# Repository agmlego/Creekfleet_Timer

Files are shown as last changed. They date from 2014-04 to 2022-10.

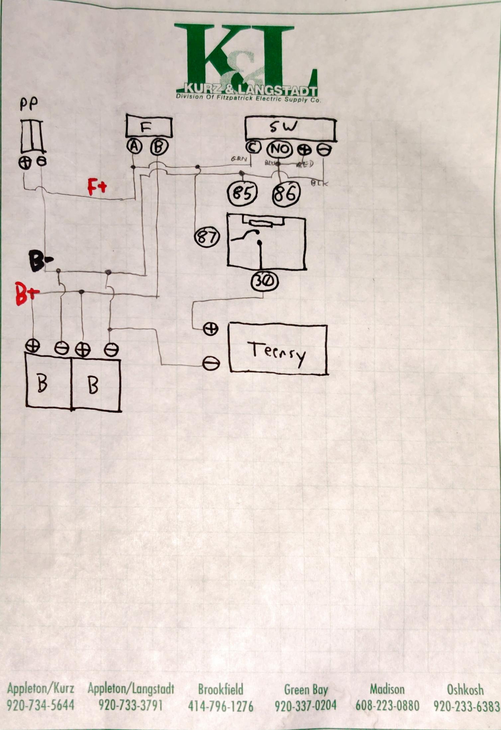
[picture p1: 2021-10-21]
hardware/electrical/battery_harness_schematic.jpg

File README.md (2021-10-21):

Creekfleet Timer
================

Automated start sequencer for the [Creekfleet](https://creekfleet.org) sailing group.

By default, runs the following sequence for each of the number of requested starts:

| Horns | Time to start |
| --- | --- |
| 3 long | 3:00 |
| 2 long | 2:00 |
| 1 long, 3 short | 1:30 |
| 1 long | 1:00 |
| 3 short | 0:30 |
| 2 short | 0:20 |
| 1 short | 0:10 |
| 1 short | 0:05 |
| 1 short | 0:04 |
| 1 short | 0:03 |
| 1 short | 0:02 |
| 1 short | 0:01 |
| 1 long | START |

Also has a mode selectable during idle operation for the ISAF Rule 26 start:

| Horns | Time to start |
| --- | --- |
| 1 short | 5:00 |
| 1 short | 4:00 |
| 1 long | 1:00 |
| 1 short | START |

## Pins

| Function | Arduino Pin |
| --- | --- |
| Horn | D12 |
| Compressor | D11 |
| Pressure Gauge| D35 (A16) |
| UP.LED | D24 |
| UP.Switch | D25 (active low) |
| DOWN.LED | D26 |
| DOWN.Switch | D27 (active low) |
| SELECT.LED | D28 |
| SELECT.Switch | D29 (active low) |
| BACK.LED | D30 |
| BACK.Switch | D31 (active low) |
| LCD.VO | A22 (DAC1) |
| LCD.RS | D13 |
| LCD.RW | D14 |
| LCD.E | D15 |
| LCD.DB0 | D16 |
| LCD.DB1 | D17 |
| LCD.DB2 | D18 |
| LCD.DB3 | D19 |
| LCD.DB4 | D20 |
| LCD.DB5 | D21 |
| LCD.DB6 | D22 |
| LCD.DB7 | D23 |
| LCD.Red BL | D36 (PWM) |
| LCD.Green BL  | D38 (PWM) |
| LCD.Blue BL | D37 (PWM) |

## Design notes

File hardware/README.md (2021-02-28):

Creekfleet Timer Hardware
=========================

EAGLE design files, case CAD files.

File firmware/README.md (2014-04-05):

Creekfleet Timer Firmware
=========================

Arduino 1.0.5 code.

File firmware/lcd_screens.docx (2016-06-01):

0123456789ABCDEFGHIJ

A CreekFleet Start

B Sequencer v2.0

C agmlego@gmail.com

D http://bit.ly/123456

0123456789ABCDEFGHIJ

A

B Number of Starts?

C > 10 <

D [UP] [DOWN] [SEL]

0123456789ABCDEFGHIJ

A Start 1/10

B 2:59 to start

C Bat 13.6V Air 89.7

D [STOP][RECALL][BLIP]

0123456789ABCDEFGHIJ

A Lock 2 HH:MM:SS.S

B Lock 1 HH:MM:SS.S

C > Live HH:MM:SS.S <

D [STOP][RECALL][BLIP]

0123456789ABCDEFGHIJ

A Short horn 250ms

B Long horn 500ms

C > Horn gap 250ms <

D [UP] [DOWN] [SEL]

0123456789ABCDEFGHIJ

A Air hyst. 20psi

B Volt warn 12.1V

C > Flag speed 250ms <

D [UP] [DOWN] [SEL]

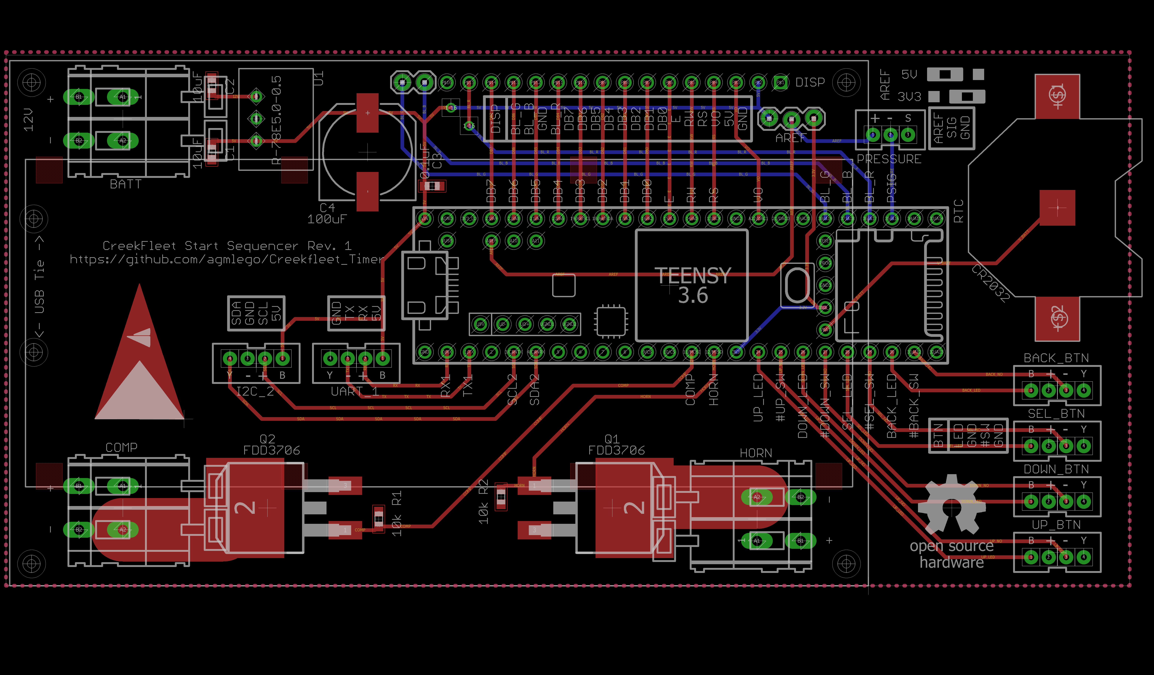
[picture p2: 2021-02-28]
hardware/electrical/mainboard_brd.png

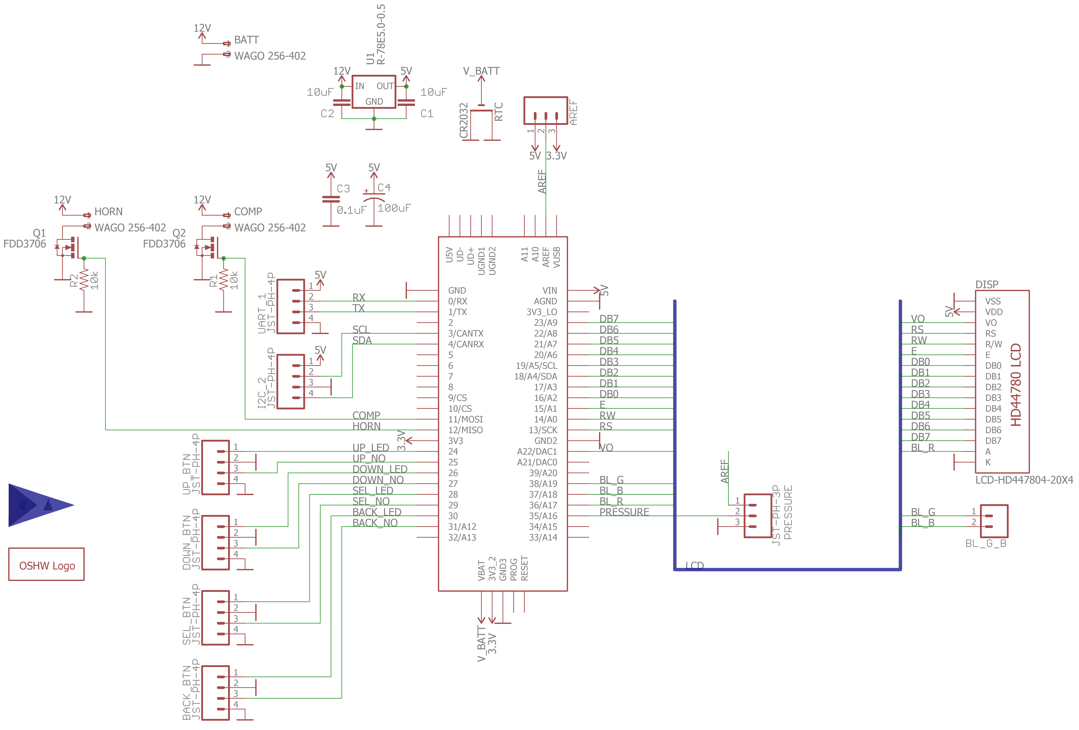
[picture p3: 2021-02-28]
hardware/electrical/mainboard_sch.png

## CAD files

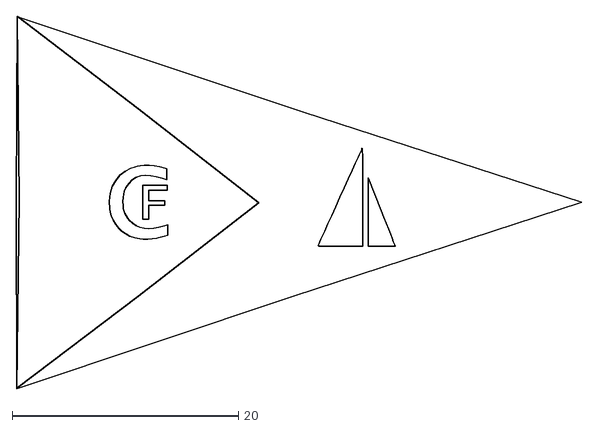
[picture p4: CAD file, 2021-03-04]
hardware/mechanical/creekfleet_logo.dxf
50.0 x 32.9

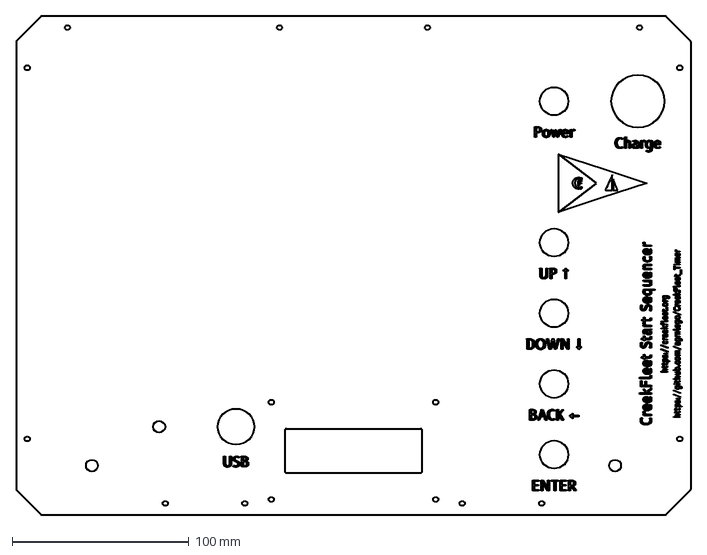
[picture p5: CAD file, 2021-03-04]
hardware/mechanical/case_panel.dxf
382.0 x 282.0 mm

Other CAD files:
hardware/mechanical/case_panel.dwg
hardware/mechanical/case_panel.ipt

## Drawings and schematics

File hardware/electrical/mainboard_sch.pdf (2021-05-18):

2021-03-12 23:05 C:\Users\agmlego\Sync\rwsir-rc7py\projects\CreekFleet\Creekfleet_Timer\hardware\electrical\mainboard.sch (Sheet: 1/1) LCD⁻HD⁴⁴⁷⁸⁰⁴⁻²⁰X4

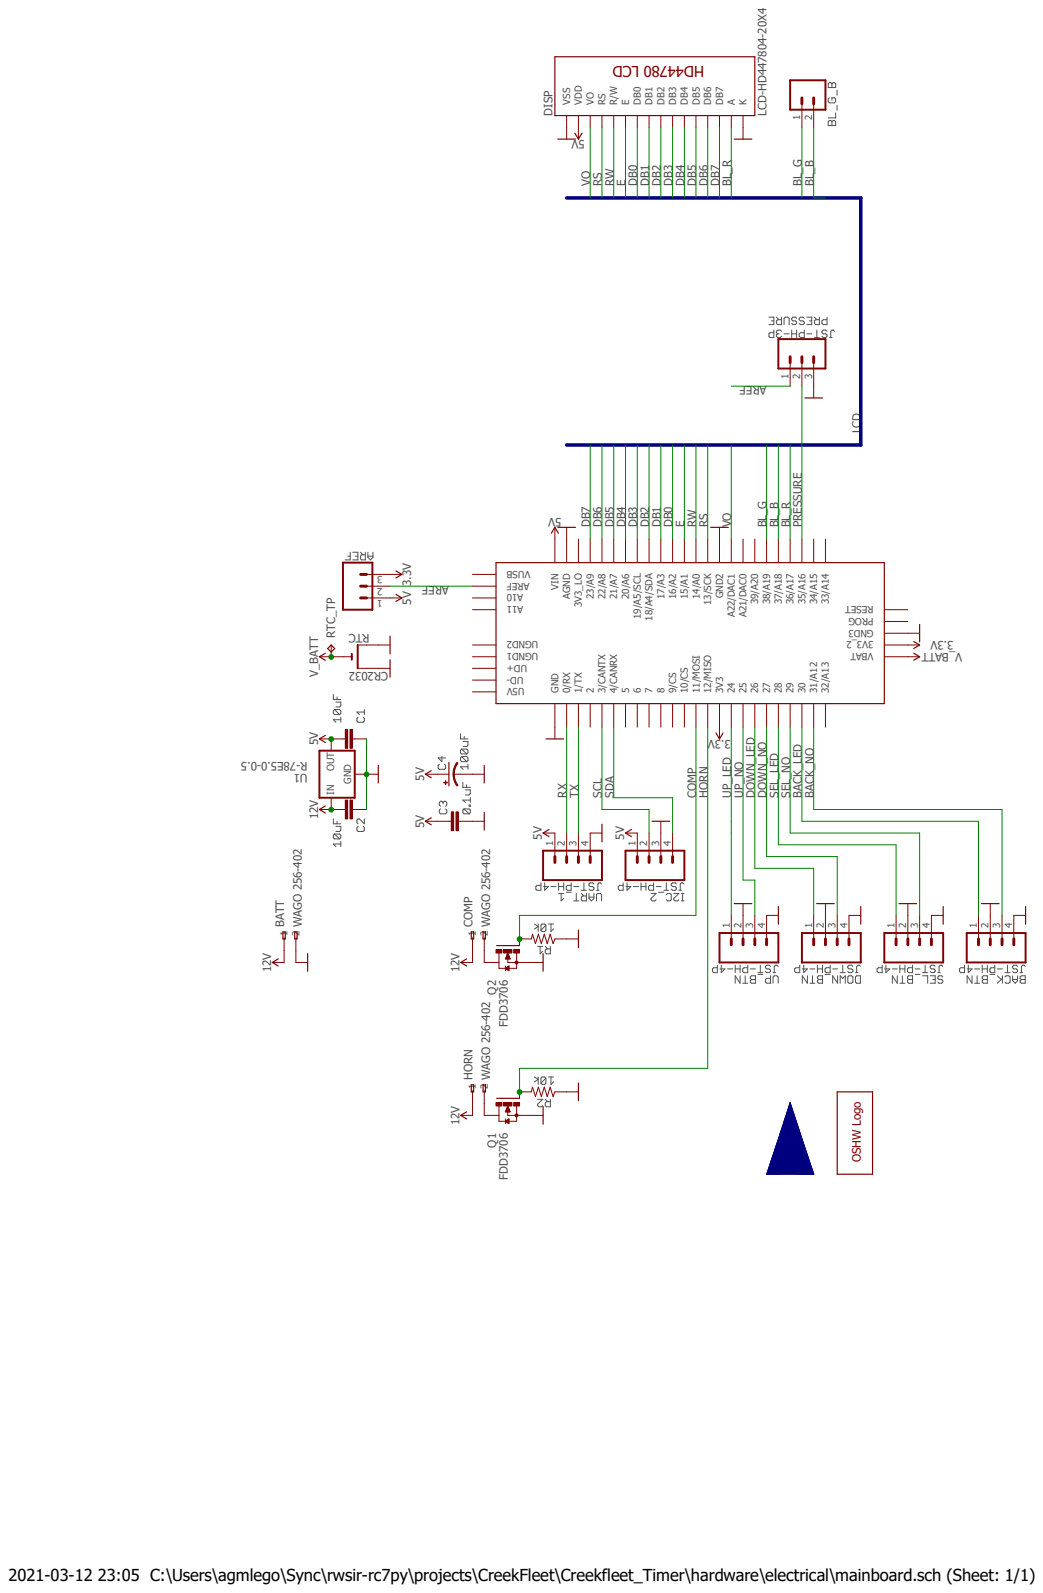
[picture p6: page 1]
23/CANTX 4/CANRX; EDB0 DB1 DB2 DB3 DB4 DB5 DB6 DB7 A

2 -1-2 BATT -1-2 HORN -1-2 COMP

89/CS 10/CS 11/MOSI 12/MISO 3V3 2425262728293031/A12 32/A13 AGND 3V3_LO 23/A9 22/A8 21/A7 20/A6 19/A5/SCL 18/A4/SDA 17/A3 16/A2 15/A1 14/A0 13/SCK GND2 A22/DAC1 A21/DAC0 39/A20 38/A19 37/A18 36/A17 35/A16 34/A15 33/A14

4 GND IN OUT U1

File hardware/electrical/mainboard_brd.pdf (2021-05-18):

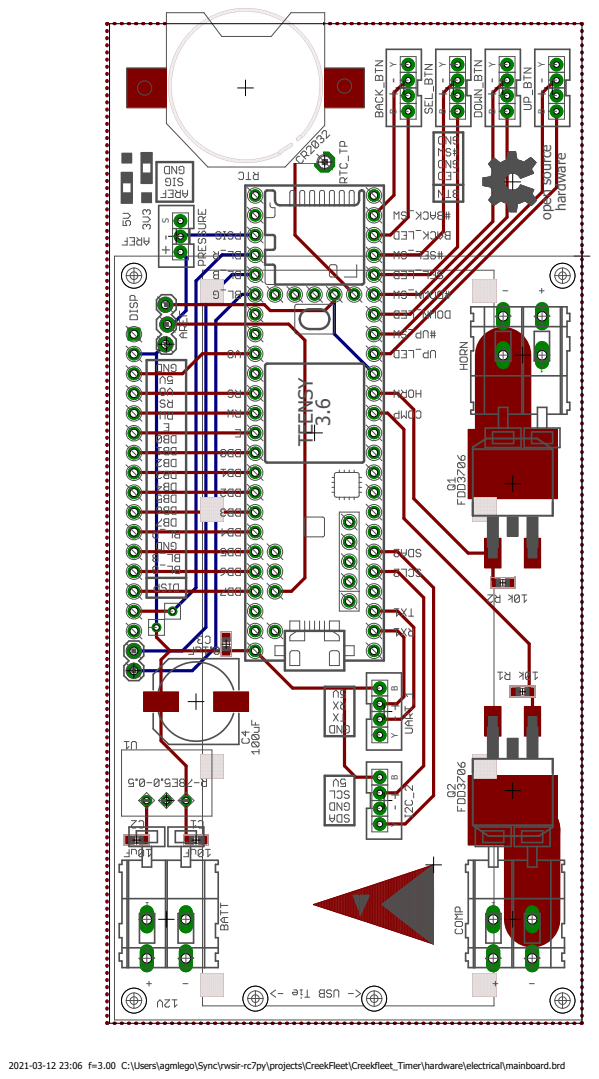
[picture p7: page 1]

B open source hardware

2021-03-12 23:06 f=3.00 C:\Users\agmlego\Sync\rwsir-rc7py\projects\CreekFleet\Creekfleet_Timer\hardware\electrical\mainboard.brd

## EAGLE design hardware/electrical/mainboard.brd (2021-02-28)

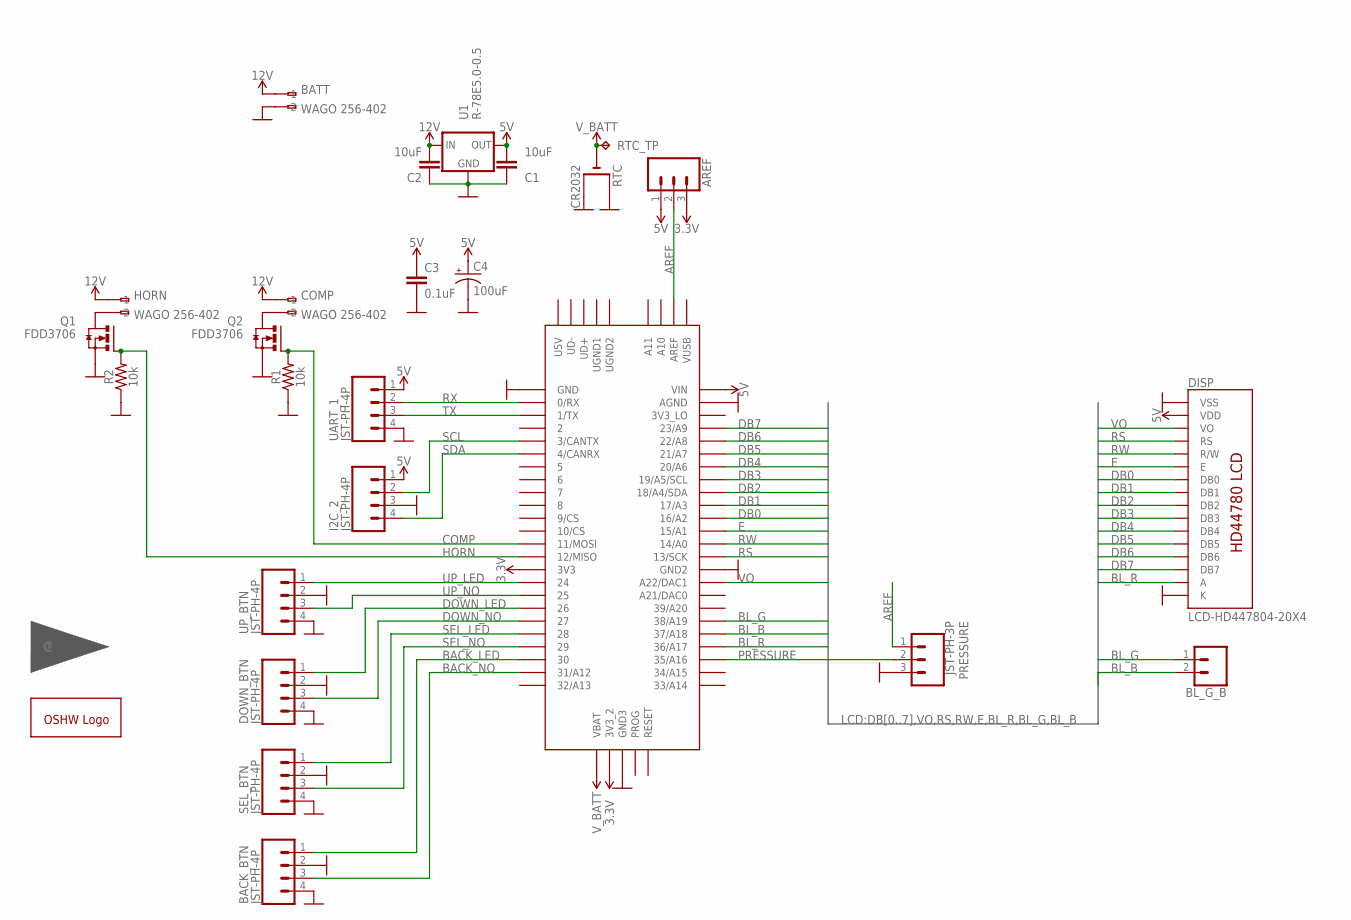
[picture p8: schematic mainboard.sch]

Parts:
AREF: CONN_03LOCK; 1X03_LOCK
BACK_BTN: JST-PH-4P; JST-4-PTH-VERT
BATT: WAGO 256-402; 255-402-5
BL_G_B: CONN_02; 1X02
C1, C2: 10uF; 0603
C3: 0.1uF; 0603
C4: 100uF; NIC_10X10.5_CAP
COMP: WAGO 256-402; 255-402-5
DISP: LCD-HD447804-20X4; LCD-20X4-4HOLES
DOWN_BTN: JST-PH-4P; JST-4-PTH-VERT
GOLD_ORB_SM1: OSHWLOGOLOGO8MM; OSHW_8MM
HORN: WAGO 256-402; 255-402-5
I2C_2: JST-PH-4P; JST-4-PTH-VERT
PRESSURE: JST-PH-3P; JST-3-PTH-VERT
Q1, Q2: FDD3706; D2PACK
R1, R2: 10k; 0603
RTC: CR2032; CR2032-SMD
RTC_TP: TPPAD1-17; P1-17
SEL_BTN: JST-PH-4P; JST-4-PTH-VERT
TEENSY: TEENSY_3.5/3.6
U1: R-78E5.0-0.5; DC-DC_CONVERTER_78XX
U$1: CFLOGO
UART_1: JST-PH-4P; JST-4-PTH-VERT
UP_BTN: JST-PH-4P; JST-4-PTH-VERT

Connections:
3.3V: AREF.3, TEENSY.3V3, TEENSY.3V3_2
5V: AREF.1, C1.2, C3.1, C4.+, DISP.P$2 (VDD), I2C_2.1, TEENSY.VIN, U1.VOUT (OUT), UART_1.1
12V: BATT.A1 (-1), C2.2, COMP.A1 (-1), HORN.A1 (-1), U1.VIN (IN)
AREF: AREF.2, PRESSURE.1, TEENSY.AREF
BACK_LED: BACK_BTN.1, TEENSY.30
BACK_NO: BACK_BTN.3, TEENSY.31/A12
BL_B: BL_G_B.2, TEENSY.37/A18
BL_G: BL_G_B.1, TEENSY.38/A19
BL_R: DISP.P$15 (A), TEENSY.36/A17
COMP: Q2.1 (G), R1.2, TEENSY.11/MOSI
DB0: DISP.P$7 (DB0), TEENSY.16/A2
DB1: DISP.P$8 (DB1), TEENSY.17/A3
DB2: DISP.P$9 (DB2), TEENSY.18/A4/SDA
DB3: DISP.P$10 (DB3), TEENSY.19/A5/SCL
DB4: DISP.P$11 (DB4), TEENSY.20/A6
DB5: DISP.P$12 (DB5), TEENSY.21/A7
DB6: DISP.P$13 (DB6), TEENSY.22/A8
DB7: DISP.P$14 (DB7), TEENSY.23/A9
DOWN_LED: DOWN_BTN.1, TEENSY.26
DOWN_NO: DOWN_BTN.3, TEENSY.27
E: DISP.P$6 (E), TEENSY.15/A1
GND: BACK_BTN.2, BACK_BTN.4, BATT.A2 (-2), C1.1, C2.1, C3.2, C4.-, DISP.P$1 (VSS), DISP.P$16 (K), DOWN_BTN.2, DOWN_BTN.4, I2C_2.3, PRESSURE.3, Q1.3 (S), Q2.3 (S), R1.1, R2.1, RTC.+$1 (+), RTC.+$2 (+1), SEL_BTN.2, SEL_BTN.4, TEENSY.AGND, TEENSY.GND, TEENSY.GND2, TEENSY.GND3, U1.GND, UART_1.4, UP_BTN.2, UP_BTN.4
HORN: Q1.1 (G), R2.2, TEENSY.12/MISO
unnamed: HORN.A2 (-2), Q1.2 (D)
unnamed: COMP.A2 (-2), Q2.2 (D)
PRESSURE: PRESSURE.2, TEENSY.35/A16
RS: DISP.P$4 (RS), TEENSY.13/SCK
RW: DISP.P$5 (R/W), TEENSY.14/A0
RX: TEENSY.0/RX, UART_1.2
SCL: I2C_2.2, TEENSY.3/CANTX
SDA: I2C_2.4, TEENSY.4/CANRX
SEL_LED: SEL_BTN.1, TEENSY.28
SEL_NO: SEL_BTN.3, TEENSY.29
TX: TEENSY.1/TX, UART_1.3
UP_LED: TEENSY.24, UP_BTN.1
UP_NO: TEENSY.25, UP_BTN.3
VO: DISP.P$3 (VO), TEENSY.A22/DAC1
V_BATT: RTC.-, RTC_TP.TP, TEENSY.VBAT

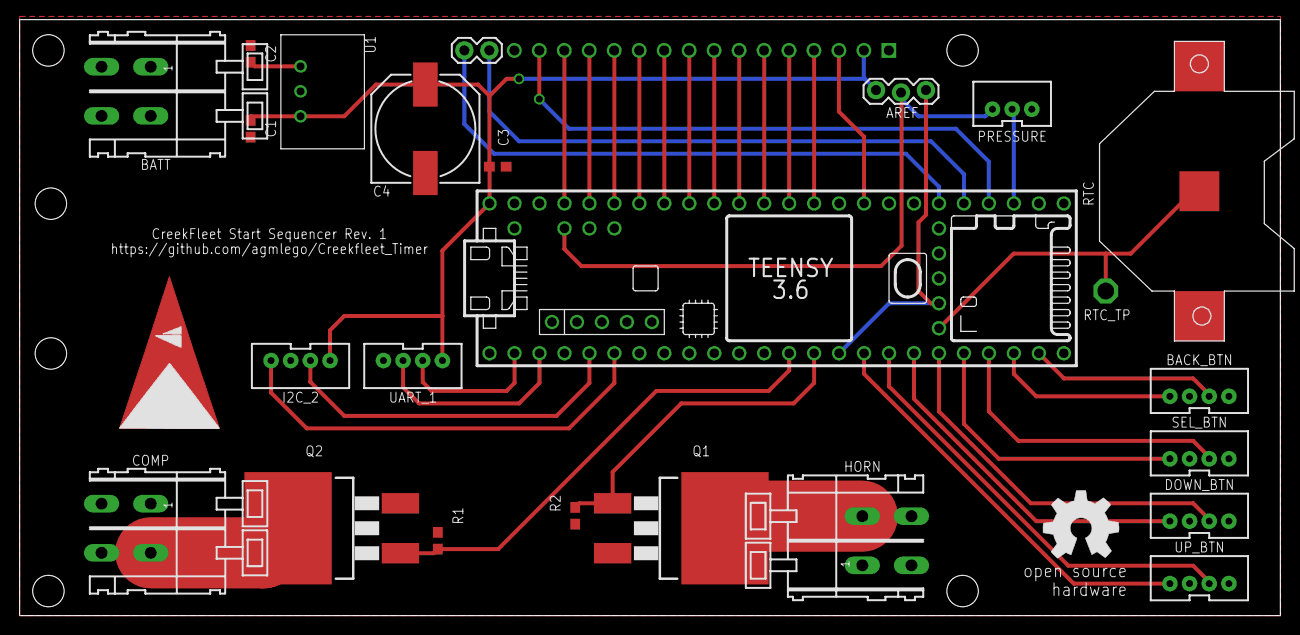
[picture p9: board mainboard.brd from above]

Board: 2 copper layers, 128.2 x 60.6 mm, 27 parts (1 on the bottom side), 38 nets.

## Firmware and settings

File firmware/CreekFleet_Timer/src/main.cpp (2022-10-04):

#include <Arduino.h>

// outside libs
#include <LiquidCrystal.h>
#include <Bounce2.h>
#include <TimeLib.h>
#include <RARGBLED.h>
#include <Chrono.h>

// Pin definitions
#include "pindefs.h"
#include "horn.h"
#include "states.h"

// Display constants
const char VERSION[] PROGMEM = "1.0.0";
char SPLASH[81] PROGMEM;
char TIME_BUF[20];
const uint8_t CONTRAST = 64; // 25% contrast voltage

// UI constants
const uint8_t DEBOUNCE = 10; // ms of debounce

// Compressor constants
const uint16_t HIGH_PRESSURE = 768;
const uint16_t LOW_PRESSURE = HIGH_PRESSURE - 128;
bool COMP_STATE = false;

// UI objects
LiquidCrystal lcd(LCD_RS, LCD_RW, LCD_E, LCD_DB0, LCD_DB1, LCD_DB2, LCD_DB3, LCD_DB4, LCD_DB5, LCD_DB6, LCD_DB7);
RARGBLED lcd_bl(LCD_BL_RED, LCD_BL_GREEN, LCD_BL_BLUE, CommonCathode);
Bounce2::Button upButton = Bounce2::Button();
Bounce2::Button downButton = Bounce2::Button();
Bounce2::Button selectButton = Bounce2::Button();
Bounce2::Button backButton = Bounce2::Button();

// Control objects
STATE programState = STATE::IDLE;
SEQUENCES sequence = SEQUENCES::CREEKFLEET;
bool latch = true;
uint8_t hornIndex = 0;
Chrono hornChrono;

void get_iso_time()
{
  sprintf(TIME_BUF, "%04d-%02d-%02d %02d:%02d:%02d",
          year(),
          month(),
          day(),
          hour(),
          minute(),
          second());
}

void cycle_buttons()
{
  digitalWrite(UP_LED, HIGH);
  delay(250);
  digitalWrite(DOWN_LED, HIGH);
  delay(250);
  digitalWrite(BACK_LED, HIGH);
  delay(250);
  digitalWrite(SELECT_LED, HIGH);
  delay(250);
  digitalWrite(UP_LED, LOW);
  delay(250);
  digitalWrite(DOWN_LED, LOW);
  delay(250);
  digitalWrite(BACK_LED, LOW);
  delay(250);
  digitalWrite(SELECT_LED, LOW);
  delay(250);
}

void setup()
{
  Serial.begin(115200);
  // Set up LCD and backlight
  lcd_bl.off();
  analogWrite(LCD_VO, CONTRAST);
  sprintf(SPLASH,
          "    CreekFleet      "
          "     Sequencer      "
          "       Start        "
          "Version%13s",
          VERSION);
  lcd.begin(20, 4);
  lcd.print(SPLASH);
  lcd_bl.setColor(COLOR::BLUE);
  Serial.println(SPLASH);

  // Set pin modes
  pinMode(HORN, OUTPUT);
  pinMode(COMPRESSOR, OUTPUT);
  pinMode(UP_LED, OUTPUT);
  pinMode(DOWN_LED, OUTPUT);
  pinMode(SELECT_LED, OUTPUT);
  pinMode(BACK_LED, OUTPUT);
  Serial.println("Pins configured!");
  upButton.attach(UP_SWITCH, INPUT_PULLUP);
  upButton.interval(DEBOUNCE);
  upButton.setPressedState(LOW);
  downButton.attach(DOWN_SWITCH, INPUT_PULLUP);
  downButton.interval(DEBOUNCE);
  downButton.setPressedState(LOW);
  selectButton.attach(SELECT_SWITCH, INPUT_PULLUP);
  selectButton.interval(DEBOUNCE);
  selectButton.setPressedState(LOW);
  backButton.attach(BACK_SWITCH, INPUT_PULLUP);
  backButton.interval(DEBOUNCE);
  backButton.setPressedState(LOW);
  Serial.println("Buttons configured!");

  cycle_buttons();

  // Set up time
  setSyncProvider(Teensy3Clock.get);
  if (timeStatus() != timeSet)
  {
    lcd.setCursor(0, 3);
    lcd.print(F("RTC is not set!     "));
    Serial.println(F("RTC is not set!     "));
  }
  else
  {
    get_iso_time();
    Serial.printf("Got good time! %s\n", TIME_BUF);
  }
}

void update_buttons()
{
  if (upButton.update())
  {
    if (upButton.pressed())
    {
      digitalWrite(UP_LED, HIGH);
      Serial.println("UP pressed");
      if (programState == STATE::IDLE)
      {
        lcd.setCursor(0, 2);
        switch (sequence)
        {
        case SEQUENCES::CREEKFLEET:
          sequence = SEQUENCES::ISAF;
          lcd.print(F("      [ISAF]        "));
          break;
        case SEQUENCES::ISAF:
          sequence = SEQUENCES::CREEKFLEET;
          lcd.print(F("   [CreekFleet]     "));
          break;
        }
      }
    }
    else
    {
      digitalWrite(UP_LED, LOW);
    }
  }
  if (downButton.update())
  {
    if (downButton.pressed())
    {
      digitalWrite(DOWN_LED, HIGH);
      Serial.println("DOWN pressed");
      if (programState == STATE::IDLE)
      {
        lcd.setCursor(0, 2);
        switch (sequence)
        {
        case SEQUENCES::CREEKFLEET:
          sequence = SEQUENCES::ISAF;
          lcd.print(F("      [ISAF]        "));
          break;
        case SEQUENCES::ISAF:
          sequence = SEQUENCES::CREEKFLEET;
          lcd.print(F("   [CreekFleet]     "));
          break;
        }
      }
    }
    else
    {
      digitalWrite(DOWN_LED, LOW);
    }
  }
  if (selectButton.update())
  {
    if (selectButton.pressed())
    {
      digitalWrite(SELECT_LED, HIGH);
      Serial.println("SELECT pressed");
      if (programState == STATE::IDLE)
      {
        programState = STATE::SEQUENCE;
        hornIndex = 0;
        lcd.clear();
        lcd.setCursor(0, 0);
        lcd_bl.setColor(COLOR::GREEN);
        lcd.print(F(" Starting sequence! "));
        lcd.setCursor(0, 1);
        lcd.print(F("Press ENTER to stop "));
        lcd.setCursor(0, 2);
        switch (sequence)
        {
        case SEQUENCES::CREEKFLEET:
          lcd.print(F("   [CreekFleet]     "));
          break;
        case SEQUENCES::ISAF:
          lcd.print(F("      [ISAF]        "));
          break;
        }
        hornChrono.restart();
      }
      else if (programState == STATE::SEQUENCE)
      {
        programState = STATE::IDLE;
        latch = true;
      }
    }
    else
    {
      digitalWrite(SELECT_LED, LOW);
    }
  }
  if (backButton.update())
  {
    if (backButton.pressed())
    {
      digitalWrite(BACK_LED, HIGH);
      Serial.println("BACK pressed");
    }
    else
    {
      digitalWrite(BACK_LED, LOW);
    }
  }
}

void update_compressor()
{
  uint16_t pressure = analogRead(PRESSURE);
  if (pressure < LOW_PRESSURE && !COMP_STATE)
  {
    COMP_STATE = true;
    digitalWrite(COMPRESSOR, HIGH);
    Serial.println("Turning ON compressor");
  }
  if (pressure > HIGH_PRESSURE && COMP_STATE)
  {
    COMP_STATE = false;
    digitalWrite(COMPRESSOR, LOW);
    Serial.println("Turning OFF compressor");
  }
}

void update_horn()
{
  switch (sequence)
  {
  case SEQUENCES::CREEKFLEET:
    if (hornChrono.hasPassed(CREEKFLEET_HORN_TIMES[hornIndex]))
    {
      Serial.printf("[%d] Turning horn ", hornIndex);
      if (CREEKFLEET_HORN_COMMANDS[hornIndex])
      {
        Serial.print("ON");
      }
      else
      {
        Serial.print("OFF");
      }
      Serial.printf(" at %d\n", CREEKFLEET_HORN_TIMES[hornIndex]);
      digitalWrite(HORN, CREEKFLEET_HORN_COMMANDS[hornIndex]);
      ++hornIndex;
    }
    if (hornIndex >= CREEKFLEET_NUM_HORNS)
    {
      Serial.println("START!");
      lcd.clear();
      lcd.setCursor(0, 2);
      lcd.write(F("       START!       "));
      cycle_buttons();
      programState = STATE::IDLE;
    }
    break;

  case SEQUENCES::ISAF:
    if (hornChrono.hasPassed(ISAF_HORN_TIMES[hornIndex]))
    {
      Serial.printf("[%d] Turning horn ", hornIndex);
      if (ISAF_HORN_COMMANDS[hornIndex])
      {
        Serial.print("ON");
      }
      else
      {
        Serial.print("OFF");
      }
      Serial.printf(" at %d\n", ISAF_HORN_TIMES[hornIndex]);
      digitalWrite(HORN, ISAF_HORN_COMMANDS[hornIndex]);
      ++hornIndex;
    }
    if (hornIndex >= ISAF_NUM_HORNS)
    {
      Serial.println("START!");
      lcd.clear();
      lcd.setCursor(0, 2);
      lcd.write(F("       START!       "));
      cycle_buttons();
      programState = STATE::IDLE;
    }
    break;
  }
}

void loop()
{
  update_buttons();
  update_compressor();
  lcd.setCursor(0, 3);
  get_iso_time();
  lcd.print(TIME_BUF);
  switch (programState)
  {
  case STATE::SEQUENCE:
    update_horn();
    break;
  case STATE::IDLE:
    if (latch)
    {
      latch = false;
      lcd_bl.setColor(COLOR::BLUE);
      lcd.clear();
      lcd.setCursor(0, 0);
      lcd.print(F("Press ENTER to start"));
      lcd.setCursor(0, 1);
      lcd.print(F("   race sequence    "));
      lcd.setCursor(0, 2);
      switch (sequence)
      {
      case SEQUENCES::CREEKFLEET:
        lcd.print(F("   [CreekFleet]     "));
        break;
      case SEQUENCES::ISAF:
        lcd.print(F("      [ISAF]        "));
        break;
      default:
        lcd.print(F("   BAD SEQUENCE     "));
        break;
      }
    }
    break;
  }
}

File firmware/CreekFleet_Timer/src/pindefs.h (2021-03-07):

#define HORN            12
#define COMPRESSOR      11
#define PRESSURE        A16
#define UP_LED          24
#define UP_SWITCH       25
#define DOWN_LED        26
#define DOWN_SWITCH     27
#define SELECT_LED      28
#define SELECT_SWITCH   29
#define BACK_LED        30
#define BACK_SWITCH     31
#define LCD_VO          A22
#define LCD_RS          13
#define LCD_RW          14
#define LCD_E           15
#define LCD_DB0         16
#define LCD_DB1         17
#define LCD_DB2         18
#define LCD_DB3         19
#define LCD_DB4         20
#define LCD_DB5         21
#define LCD_DB6         22
#define LCD_DB7         23
#define LCD_BL_RED      36
#define LCD_BL_BLUE     37
#define LCD_BL_GREEN    38

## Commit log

2014-04-05 Pin setup complete, header file populated.
2016-06-01 Update with CAD, board files, and new firmware.
    [01.0002.ipt, 01.ipt, 02.0001.ipt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]
2016-06-08 Laid out compressor driver.
    [remote.brd, remote.sch]
2016-07-09 Cleaned up code for data types, assigned flag pins for remote, modified README.md with pin assignments.
2016-07-09 Drawings created for prints (machining) and printing (drill hole spotting). STL created for 3D printing.
    [Drum_Key&Shaft.dwg, Housing.0001.dwg, Housing.0003.dwg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]
2016-08-13 Added connector details for remote
2016-08-13 Corrected image links
    Using rawgit to serve connector images, per isaacs/github#316
2021-02-28 Preparation for new design, horns-only
    [01.0002.ipt, 01.ipt, 02.0001.ipt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]
2021-02-28 New board design for horn-only operation
    [mainboard.brd, mainboard.sch]
2021-02-28 added testpoint for RTC battery
    [mainboard.brd, mainboard.sch]
2021-02-28 Fixed copper under CR2032 holder
    [mainboard.brd]
2021-03-04 Added CAD for case panel
    [case_panel.dwg, case_panel.dxf, case_panel.ipt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]
2021-03-07 "Pin definitions and some setup."
2021-03-07 "Time print from RTC"
2021-05-18 Added PDF board art
2021-05-19 Power-on LED test
2021-05-19 Removed original Arduino firmware

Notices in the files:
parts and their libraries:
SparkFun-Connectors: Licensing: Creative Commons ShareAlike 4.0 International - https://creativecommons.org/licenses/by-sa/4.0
